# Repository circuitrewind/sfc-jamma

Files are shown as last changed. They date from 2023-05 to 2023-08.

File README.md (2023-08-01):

# sfc-jamma

TLDR: SNES/SFC controller support on arcade machines!

[Click here for a demo video of a Capcom CP Solder used to play Street Fighter Zero 3](https://www.tiktok.com/@vincerants/video/7230315835842170155)

This repository contains the Eagle CAD files as well as the Arduino Nano source code to interface a Super Famicom (SFC) or Super Nintendo (SNES) controller with an Arcade Cabinet JAMMA interface via a 40-pin ribbon cable.

The 40-pin ribbon cable pinout is based on the pinout used by the [EZ Switchers by RiddledTV](https://riddledtv.com/arcade/ez.html). The EZ 4-way Switcher and EZ 8-way Switcher provide both a JAMMA edge and 40-pin output connectors with the intent of having two cabinets wired into the same arcade board for head-to-head gameplay. I abused this fact to instead use the 40-pin cable for a secondary set of user input controls.

Because the wiring on the JAMMA interface and 40-pin interface are tied directly together, the Arduino Nano can also read input from the arcade's input panel, and then forward this information over the Arduino Nano's USB interface back to a PC, such as using it for gamepad emulation. This can be useful for running a PC through an arcade cabinet, and forwarding the input controls from the cabinet back into the PC.

## Button Mappings
On Player 1, hold SELECT + START for two seconds to toggle TEST / SETTINGS button. This is set as a toggle rather than a momentary press because some games like Soul Edge require the button to remain held while in the settings menu.

On Player 2, hold SELECT + START for two seconds to toggle TILT button. P1 and P2 Arduino Nanos run on the same code, which is why this is also a held toggle function.

Press SELECT + UP to select Profile 1
Press SELECT + DOWN to select Profile 2

|SNES|NES|Profile 1|Profile 2|
|---|---|---|---|
|SELECT|SELECT|Insert Coin|Insert Coin|
|START|START|Player Start|Player Start|
|A||Button 5 (MK)|Button 6 (HK)|
|B|A|Button 4 (LK)|Button 4 (LK)|
|X||Button 2 (MP)|Button 3 (HP)|
|Y|B|Button 1 (LP)|Button 1 (LP)|
|L||Button 3 (HP)|Button 2 (MP)|
|R||Button 6 (HK)|Button 5 (MK)|

## Tested SNES Controllers
* Nintendo Super NES Controller: SNS-005
* Nintendo Super Famicom Controller: SHVC-005
* Nintendo Super NES Score Master: SNSP-026
* NTT Data Key Pad: NDK10 (1)
* Brook Gaming Wingman SNES Converter: ZPP005Q
* 8BitDo Retro Receiver for SNES
* Capcom CP Soldier: CP-S01CAN
* HORI Fatal Fury 2 Commander Controller: HSG-07
* HORI Fighting Commander: HSJ-14
* Hudson Soft Super Joycard: HC-691
* Asciiware AsciiPad: AS-131-SP
* Asciiware Super Advantage: 4910
* Asciiware Fight Stick: AS-9981-SF
* STD SN ProPad: SV-334
* STD SN ProgramPad: SV-337
* Triax Turbo Touch 360
* Tyco Super NES Power Plug: 1286
* Konami Hissatsu Command Controller: RU-009
* High Frequency Clear Turbo Controller for SNES
* FC2 Slim
* Hyperkin Retron 2 Controller: M05932

(1) The NTT Data Key Pad will always have bit 14 pressed (outside of the normal buttons). The four high bits are used to identify the type of device plugged into a controller port, with value 0h being a normal controller. This has a value of 2h, and it most likely used by the accompanying hardware to identify itself and tell the software to do extra querying on the controller to read its additional buttons.

## Tested NES Controllers
* Nintendo Controller: NES-004
* Nintendo NES MAX: NES-027
* 8BitDo N30 2.4g Wireless Gamepad: 81BC
* Brook Gaming Wingman SNES Converter: ZPP005Q

## Images
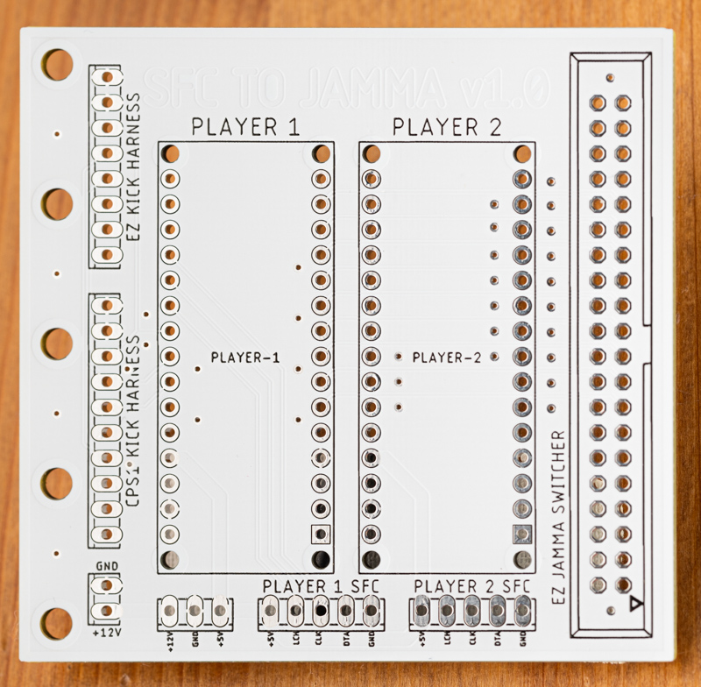
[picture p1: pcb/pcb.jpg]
SFC to JAMMA PCB


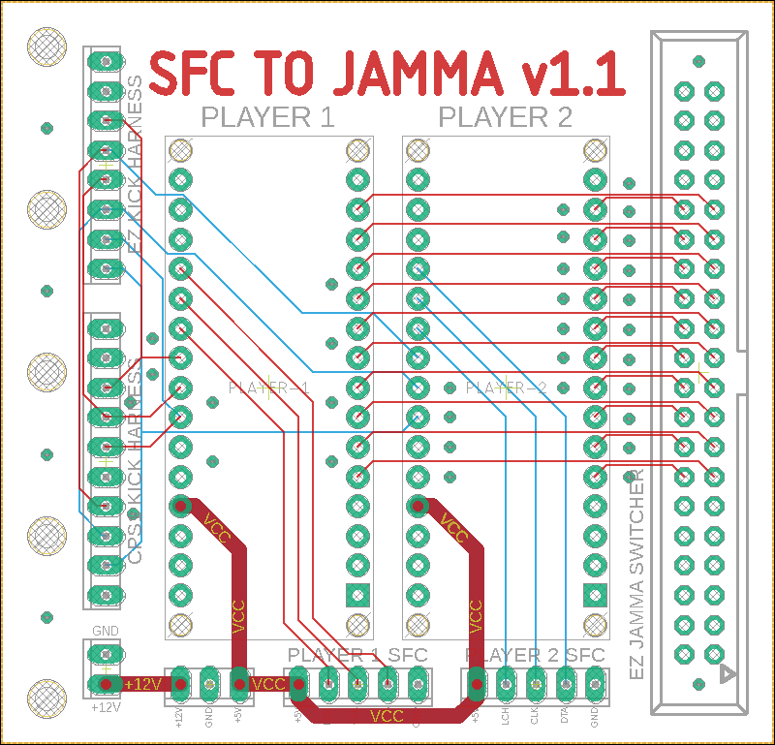
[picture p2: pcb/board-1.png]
SFC to JAMMA Board Layout


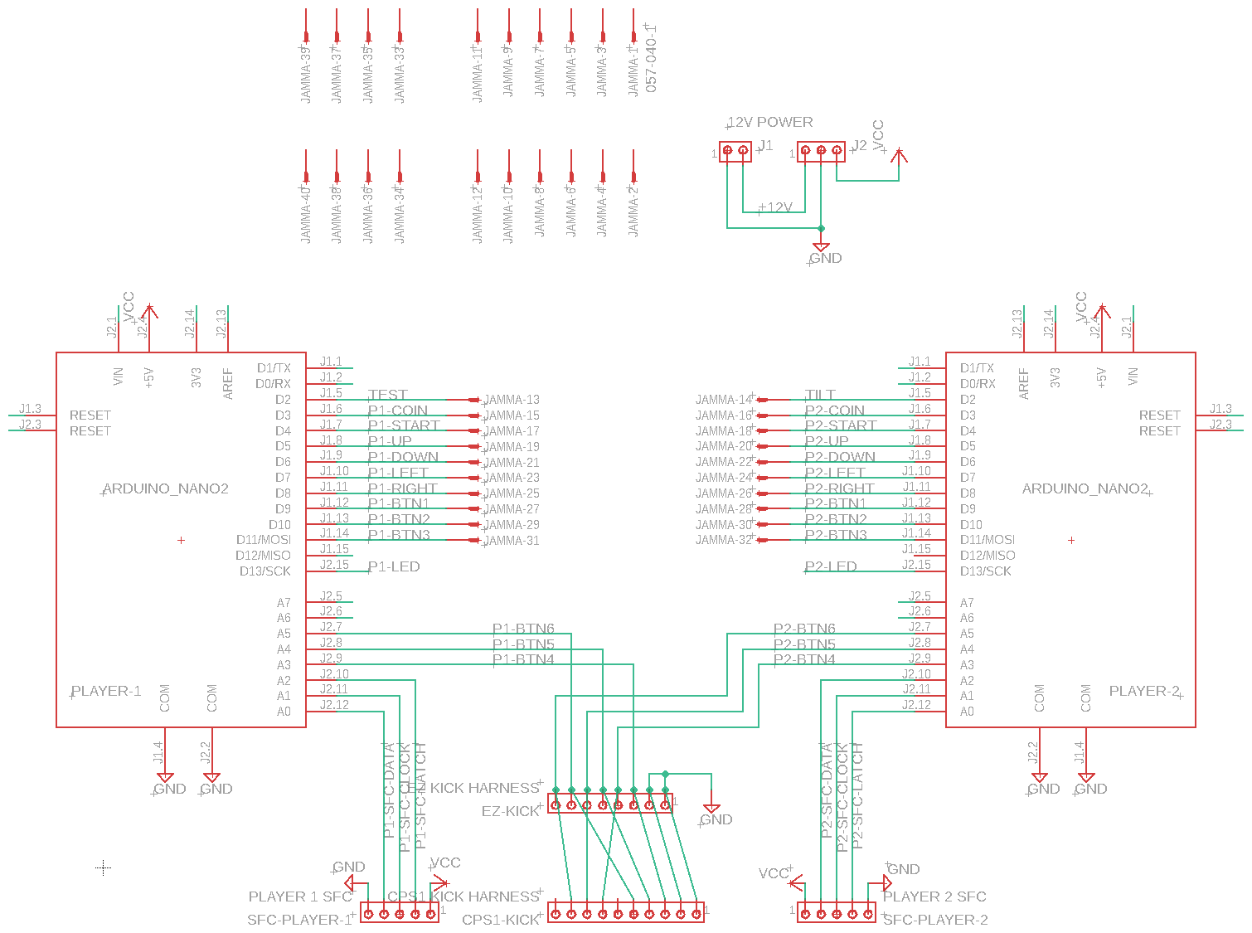
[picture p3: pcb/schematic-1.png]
SFC to JAMMA Schematic


## vJoy IBUS PC Access
To use this board with a PC, allowing SNES/SFC or JAMMA input as a PC gamepad, you'll need a couple of utilities installed and configured on your PC.
* [vJoy](https://sourceforge.net/projects/vjoystick/)
* [vJoySerialFeeder](https://github.com/Cleric-K/vJoySerialFeeder/releases)
* [Video of JAMMA to PC with Street Fighter 6](https://www.tiktok.com/@vincerants/video/7229858727111888174)

### vJoy Configuration
* Download and install [vJoy](https://sourceforge.net/projects/vjoystick/)
* Make sure that "Enable vJoy" is selected
* Uncheck all but "X" and "Y" from Axes
* Set the number of buttons to 16
* Set "POVs" to "0" in the "POV Hat Switch" panel
* Unchecked "Enable Effects" in the "Force Feedback" panel
* Click the "Apply" button

### vJoySerialFeeder Configuration
* Download and run [vJoySerialFeeder](https://github.com/Cleric-K/vJoySerialFeeder/releases)
* Set "Virtual Joystick" to "vJoy.1"
* Set "Protocol" to "IBUS"
* Click the "Setup" button next to "IBUS" and enable "Use 16-bit channels (Arduino)"
* Set "Port" to the COM port your Arduino Nano is registering to on your PC
* Click "Add Bit-mapped Button" once and "Add Axis" twice to add the three channels this board provides
* Set the "Bits" channel to "1", and configure the individual buttons as: 1, 3, 7, 8, nc, nc, nc, nc, 2, 4, 5, 6, nc, nc, nc, nc
* Set the axis channels to 2 for X, and 3 for Y
* In each axis channel, click their "Setup" button and set: Minimum=0, Center=32768, Maximum=65535
* Once everything is configured click on the "Connect" button to activate the interface

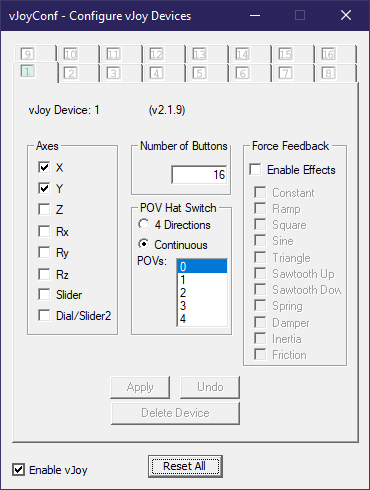
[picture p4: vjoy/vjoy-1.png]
vJoy configuration screen


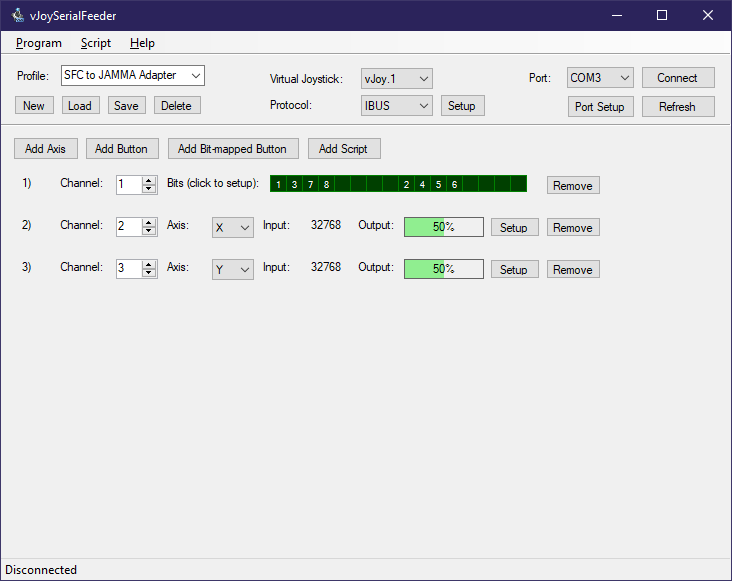
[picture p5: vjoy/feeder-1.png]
vJoySerialFeeder configuration screen


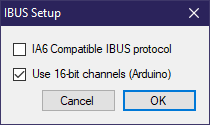
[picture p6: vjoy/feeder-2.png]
vJoySerialFeeder IBUS configuration screen


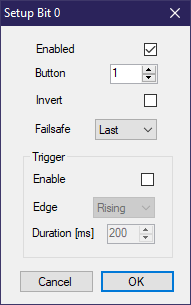
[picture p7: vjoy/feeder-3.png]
vJoySerialFeeder bit-mapped button configuration screen


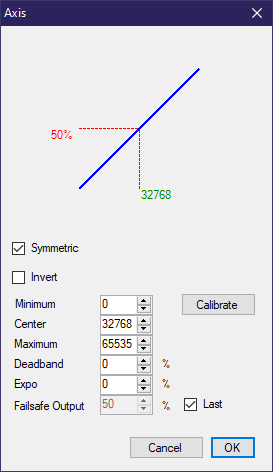
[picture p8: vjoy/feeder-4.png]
vJoySerialFeeder axis configuration screen


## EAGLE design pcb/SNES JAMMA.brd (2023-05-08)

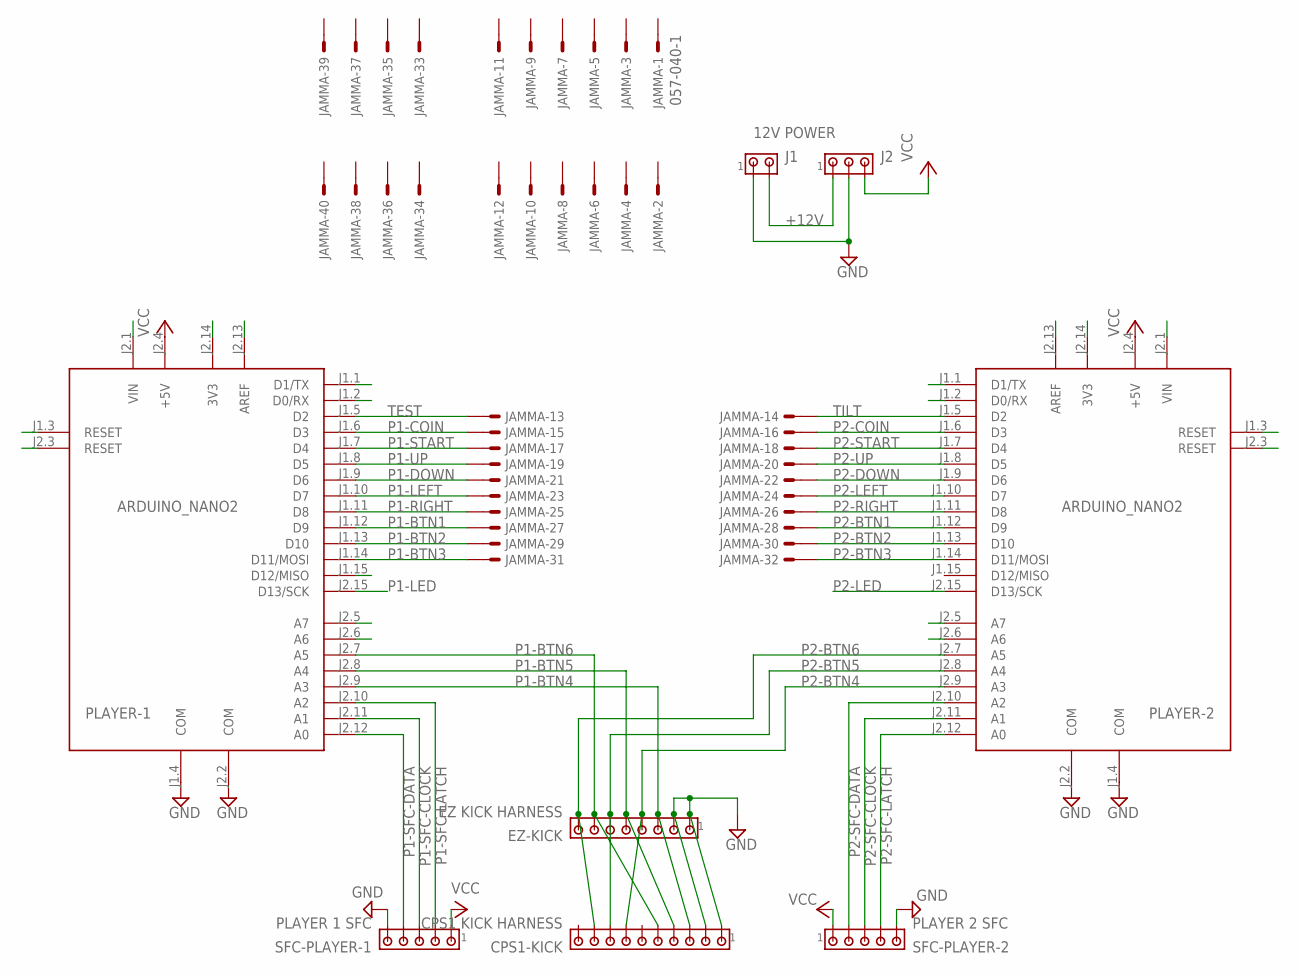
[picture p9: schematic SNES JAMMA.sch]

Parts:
CPS1-KICK: CPS1 KICK HARNESS; 10X10MTA
EZ-KICK: EZ KICK HARNESS; 10X08MTA
J1: 12V POWER; 10X02MTA
J2: MTA03-100; 10X03MTA
JAMMA: 057-040-1
PLAYER-1, PLAYER-2: ARDUINO_NANO2
SFC-PLAYER-1: PLAYER 1 SFC; 10X05MTA
SFC-PLAYER-2: PLAYER 2 SFC; 10X05MTA

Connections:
+12V: J1.2, J2.1
GND: CPS1-KICK.1, CPS1-KICK.2, EZ-KICK.1, EZ-KICK.2, J1.1, J2.2, PLAYER-1.J1.4 (COM), PLAYER-1.J2.2 (COM), PLAYER-2.J1.4 (COM), PLAYER-2.J2.2 (COM), SFC-PLAYER-1.5, SFC-PLAYER-2.5
P1-BTN1: JAMMA.27, PLAYER-1.J1.12 (D9)
P1-BTN2: JAMMA.29, PLAYER-1.J1.13 (D10)
P1-BTN3: JAMMA.31, PLAYER-1.J1.14 (D11/MOSI)
P1-BTN4: CPS1-KICK.3, EZ-KICK.3, PLAYER-1.J2.9 (A3)
P1-BTN5: CPS1-KICK.4, EZ-KICK.5, PLAYER-1.J2.8 (A4)
P1-BTN6: CPS1-KICK.5, EZ-KICK.7, PLAYER-1.J2.7 (A5)
P1-COIN: JAMMA.15, PLAYER-1.J1.6 (D3)
P1-DOWN: JAMMA.21, PLAYER-1.J1.9 (D6)
P1-LED: PLAYER-1.J2.15 (D13/SCK)
P1-LEFT: JAMMA.23, PLAYER-1.J1.10 (D7)
P1-RIGHT: JAMMA.25, PLAYER-1.J1.11 (D8)
P1-SFC-CLOCK: PLAYER-1.J2.11 (A1), SFC-PLAYER-1.3
P1-SFC-DATA: PLAYER-1.J2.12 (A0), SFC-PLAYER-1.4
P1-SFC-LATCH: PLAYER-1.J2.10 (A2), SFC-PLAYER-1.2
P1-START: JAMMA.17, PLAYER-1.J1.7 (D4)
P1-UP: JAMMA.19, PLAYER-1.J1.8 (D5)
P2-BTN1: JAMMA.28, PLAYER-2.J1.12 (D9)
P2-BTN2: JAMMA.30, PLAYER-2.J1.13 (D10)
P2-BTN3: JAMMA.32, PLAYER-2.J1.14 (D11/MOSI)
P2-BTN4: CPS1-KICK.7, EZ-KICK.4, PLAYER-2.J2.9 (A3)
P2-BTN5: CPS1-KICK.8, EZ-KICK.6, PLAYER-2.J2.8 (A4)
P2-BTN6: CPS1-KICK.9, EZ-KICK.8, PLAYER-2.J2.7 (A5)
P2-COIN: JAMMA.16, PLAYER-2.J1.6 (D3)
P2-DOWN: JAMMA.22, PLAYER-2.J1.9 (D6)
P2-LED: PLAYER-2.J2.15 (D13/SCK)
P2-LEFT: JAMMA.24, PLAYER-2.J1.10 (D7)
P2-RIGHT: JAMMA.26, PLAYER-2.J1.11 (D8)
P2-SFC-CLOCK: PLAYER-2.J2.11 (A1), SFC-PLAYER-2.3
P2-SFC-DATA: PLAYER-2.J2.12 (A0), SFC-PLAYER-2.4
P2-SFC-LATCH: PLAYER-2.J2.10 (A2), SFC-PLAYER-2.2
P2-START: JAMMA.18, PLAYER-2.J1.7 (D4)
P2-UP: JAMMA.20, PLAYER-2.J1.8 (D5)
TEST: JAMMA.13, PLAYER-1.J1.5 (D2)
TILT: JAMMA.14, PLAYER-2.J1.5 (D2)
VCC: J2.3, PLAYER-1.J2.4 (+5V), PLAYER-2.J2.4 (+5V), SFC-PLAYER-1.1, SFC-PLAYER-2.1

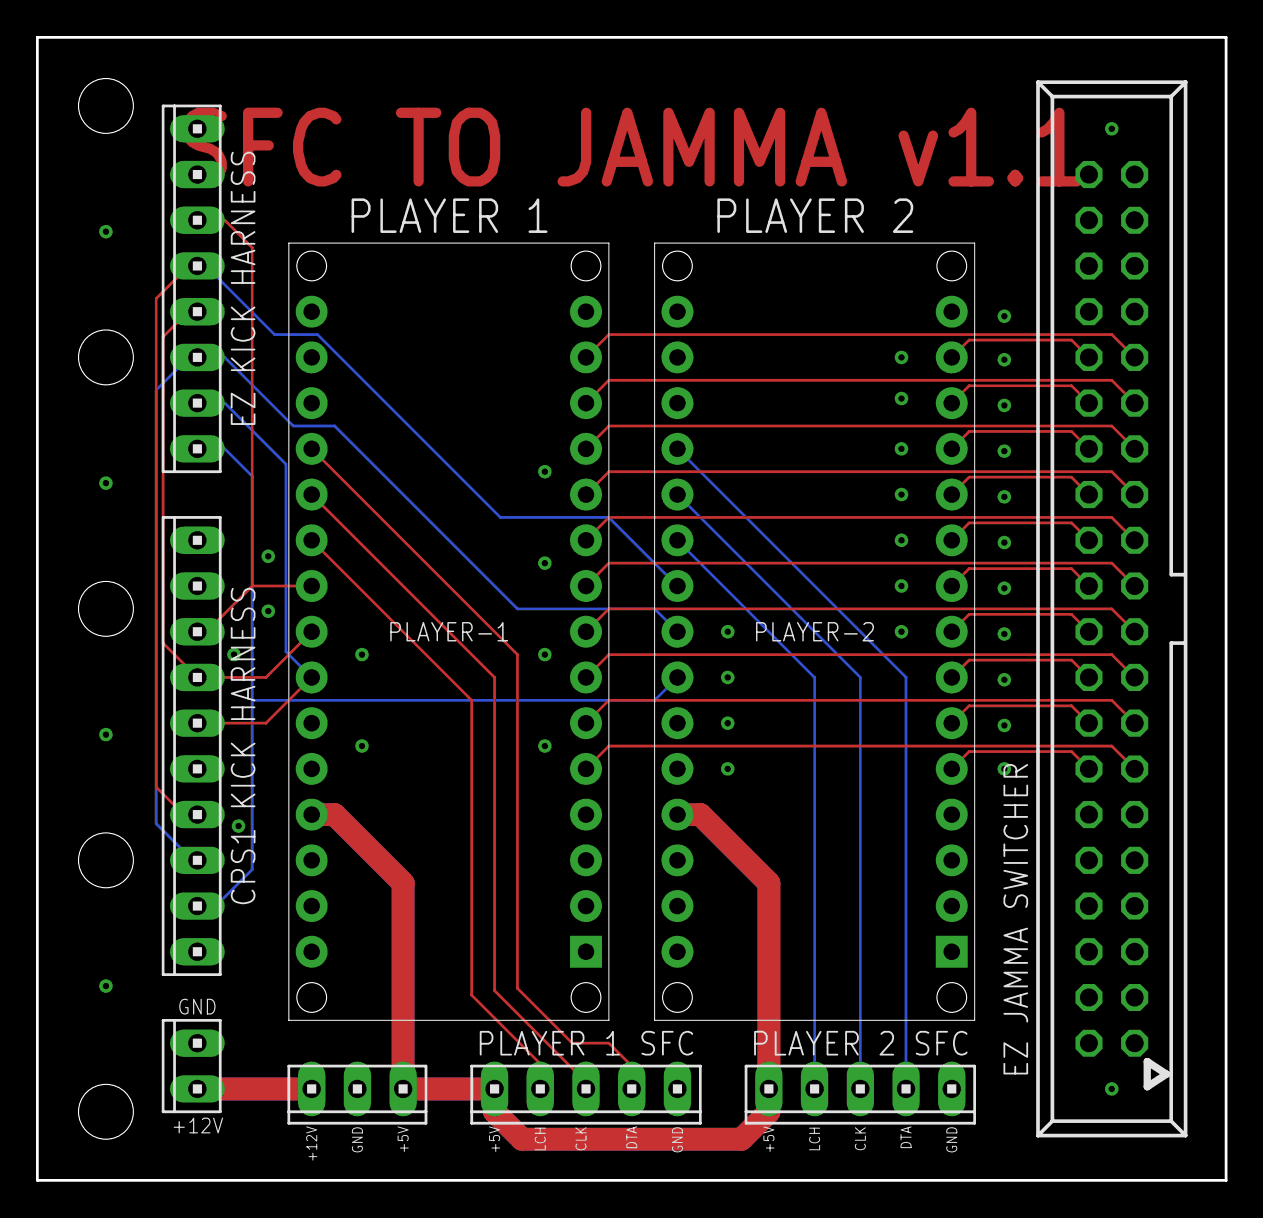
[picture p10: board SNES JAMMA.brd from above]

Board: 2 copper layers, 66.0 x 63.5 mm, 9 parts (0 on the bottom side), 35 nets.

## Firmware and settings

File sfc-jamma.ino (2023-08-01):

////////////////////////////////////////////////////////////////////////////////
// SFC PROFILE CONFIGURATION
////////////////////////////////////////////////////////////////////////////////
#define BUTTON_MAX    (16)
#define PROFILE_MAX    (2)
int profile             = 0;
unsigned int  held_btns = 0;
unsigned long held_time = 0;
bool          held_test = false;




////////////////////////////////////////////////////////////////////////////////
// SFC PIN CONFIGURATION
////////////////////////////////////////////////////////////////////////////////
#define DATA_SERIAL   (14)
#define DATA_CLOCK    (15)
#define DATA_LATCH    (16)




////////////////////////////////////////////////////////////////////////////////
// JAMMA BUTTON 
////////////////////////////////////////////////////////////////////////////////
#define P1_TEST        (2)
#define P1_COIN        (3)
#define P1_START       (4)
#define P1_UP          (5)
#define P1_DOWN        (6)
#define P1_LEFT        (7)
#define P1_RIGHT       (8)
#define P1_LP          (9)
#define P1_MP         (10)
#define P1_HP         (11)
#define P1_LK         (17)
#define P1_MK         (18)
#define P1_HK         (19)




////////////////////////////////////////////////////////////////////////////////
// IBUS CONFIGURATION FOR SENDING BUTTONS BACK TO
// PC OVER SERIAL/USB INTERFACE
////////////////////////////////////////////////////////////////////////////////
#define ibus_baud     (115200)
#define ibus_sep      (0x40)
#define ibus_channels (3)
#define ibus_len      (4 + (ibus_channels * 2))
int ibus_checksum     = 0;




////////////////////////////////////////////////////////////////////////////////
// CONSTANT TIME DELAY CODE
// BROOK SNES ADAPTERS ARE UNSTABLE AT 6MS, BUT STABLE AT 7MS
// ADD AN EXTRA 0.5MS TO ENSURE A MARGIN OF ERROR
////////////////////////////////////////////////////////////////////////////////
unsigned long time;
#define time_delay    (7500)




////////////////////////////////////////////////////////////////////////////////
// BUTTON MAPPING PROFILES
////////////////////////////////////////////////////////////////////////////////
const byte P1[PROFILE_MAX][BUTTON_MAX] = {
  {
    P1_LK,
    P1_LP,
    P1_COIN,
    P1_START,
    P1_UP,
    P1_DOWN,
    P1_LEFT,
    P1_RIGHT,
    P1_MK,
    P1_MP,
    P1_HP,
    P1_HK,
    0xFF,
    0xFF,
    0xFF,
    0xFF,
  }, {
    P1_LK,
    P1_LP,
    P1_COIN,
    P1_START,
    P1_UP,
    P1_DOWN,
    P1_LEFT,
    P1_RIGHT,
    P1_HK,
    P1_HP,
    P1_MP,
    P1_MK,
    0xFF,
    0xFF,
    0xFF,
    0xFF,
  }
};




////////////////////////////////////////////////////////////////////////////////
// READ DATA FROM THE SFC SERIAL BUS
////////////////////////////////////////////////////////////////////////////////
unsigned int read_button() {
  unsigned int buttons = 0x0000;

  // INITIATE A LATCHING SEQUENCE
  digitalWrite(DATA_LATCH, HIGH);
  delayMicroseconds(12);
  digitalWrite(DATA_LATCH, LOW);

  // LOOP THROUGH EACH BUTTON AND READ ITS VALUE
  for(int i=0; i<BUTTON_MAX; i++){
    delayMicroseconds(6);
    digitalWrite(DATA_CLOCK, LOW);
    delayMicroseconds(6);
    buttons |= (!!digitalRead(DATA_SERIAL)) << i;
    digitalWrite(DATA_CLOCK, HIGH);
  }

  // CONTROLLER APPEARS UNPLUGGED
  // PROCESS AS NO BUTTONS PRESSED INSTEAD
  if (buttons == 0x0000) buttons = 0xFFFF;

  // NES CONTROLLER SUPPORT
  // UNSET HIGH BITS IF WE DETECT 8-BIT NES CONTROLLERS
  if ((buttons & 0xFF00) == 0x0000) {
    buttons |= 0xFF00;
  }

  return buttons;
}




////////////////////////////////////////////////////////////////////////////////
// BEGIN AN IBUS TRANSMISSION
////////////////////////////////////////////////////////////////////////////////
void ibus_start() {
  ibus_checksum = 0xffff - ibus_len - ibus_sep;
  Serial.write(ibus_len);
  Serial.write(ibus_sep);
}




////////////////////////////////////////////////////////////////////////////////
// END AN IBUS TRANSMISSION
////////////////////////////////////////////////////////////////////////////////
void ibus_end() {
  Serial.write(ibus_checksum & 0xff);
  Serial.write(ibus_checksum >> 8);
}




////////////////////////////////////////////////////////////////////////////////
// SEND AN IBUS MESASGE
////////////////////////////////////////////////////////////////////////////////
void ibus_write(unsigned short data) {
  // WRITE FIRST BYTE
  byte b = data & 0xff;
  Serial.write(b);
  ibus_checksum -= b;

  // WRITE SECOND BYTE
  b = data >> 8;
  Serial.write(b);
  ibus_checksum -= b;
}




////////////////////////////////////////////////////////////////////////////////
// TOGGLE TEST/SETTINGS BUTTON WHEN START+SELECT HELD FOR 2 SECONDS
////////////////////////////////////////////////////////////////////////////////
void test_button() {
  if (micros() - held_time < 2000000) return;

  held_btns = 0x0000;
  held_test = !held_test;

  if (held_test) {
    pinMode(P1_TEST, OUTPUT);
    digitalWrite(P1_TEST, LOW);
  } else {
    pinMode(P1_TEST, INPUT_PULLUP);
  }
}




////////////////////////////////////////////////////////////////////////////////
// MAIN INITIALIZATION CODE
////////////////////////////////////////////////////////////////////////////////
void setup() {
  
  // initialize pin LED_BUILTIN as an output.
  pinMode(LED_BUILTIN, OUTPUT);
  digitalWrite(LED_BUILTIN, LOW);

  // INITIALIZE PIN FOR TEST MODE
  pinMode(P1_TEST, INPUT_PULLUP);

  // SET ALL JAMMA PINS TO "INPUT" MODE
  for (int i=0; i<BUTTON_MAX; i++) {
    if (P1[profile][i] == 0xFF) continue;
    pinMode(P1[profile][i], INPUT_PULLUP);
  }
  
  // SET DATA_CLOCK NORMALLY HIGH
  pinMode(DATA_CLOCK, OUTPUT);
  digitalWrite(DATA_CLOCK, HIGH);
  
  // SET DATA_LATCH NORMALLY LOW
  pinMode(DATA_LATCH, OUTPUT);
  digitalWrite(DATA_LATCH, LOW);

  // SET DATA_SERIAL NORMALLY HIGH
  pinMode(DATA_SERIAL, OUTPUT);
  digitalWrite(DATA_SERIAL, HIGH);
  pinMode(DATA_SERIAL, INPUT_PULLUP);

  // SETUP SERIAL FOR IBUS
  Serial.begin(ibus_baud);

  // GET INITIAL TIMEFRAME
  time = micros();
}




////////////////////////////////////////////////////////////////////////////////
// MAIN PROGRAM LOOP
////////////////////////////////////////////////////////////////////////////////
void loop() {
  // READ THE CURRENT BUTTON STATE
  unsigned int    buttons = read_button();
  unsigned int    jamma   = 0;
  unsigned short  jamma_x = 0x8000;
  unsigned short  jamma_y = 0x8000;


  // LIGHT UP ARDUINO LED IF ANY SFC BUTTONS ARE PRESSED
  digitalWrite(LED_BUILTIN, (buttons != 0xFFFF));


  // BUTTON STATE CHANGED FROM LAST POLL TIME
  if (held_btns != buttons) {
    held_btns = buttons;
    held_time = micros();
  }


  // SWITCH BETWEEN JAMMA BUTTON MAPPING PROFILES
  switch (~buttons) {
    case 0x0014:  profile = 0;    break;
    case 0x0024:  profile = 1;    break;

    // TEST BUTTON TOGGLE
    case 0x000C:  test_button();  break;
  }


  // PROCESS BUTTON DATA
  for (int i=0; i<BUTTON_MAX; i++) {
    int btn = P1[profile][i];
    if (btn == 0xFF) continue;


    // SFC BUTTON NOT PRESSED, READ JAMMA BUTTON INSTEAD
    if (buttons & (0x01 << i)) {
      pinMode(btn, INPUT_PULLUP);
      if (digitalRead(btn) == LOW) {
        jamma |= (0x01 << i);

        // PROCESS ARCADE JOYSTICK
        switch (btn) {
          case P1_LEFT:   jamma_x = 0x0000; break;
          case P1_RIGHT:  jamma_x = 0xffff; break;
          case P1_UP:     jamma_y = 0x0000; break;
          case P1_DOWN:   jamma_y = 0xffff; break;
        }
      }


    // SEND SFC BUTTON PRESS TO JAMMA
    } else {
      pinMode(btn, OUTPUT);
      digitalWrite(btn, LOW);

      // PROCESS SFC D-PAD
      switch (btn) {
        case P1_LEFT:   jamma_x = 0x0000; break;
        case P1_RIGHT:  jamma_x = 0xffff; break;
        case P1_UP:     jamma_y = 0x0000; break;
        case P1_DOWN:   jamma_y = 0xffff; break;
      }
    }
  }


  // SEND SFC AND JAMMA BUTTON STATUS TO IBUS
  ibus_start();
  ibus_write(jamma | (~buttons));
  ibus_write(jamma_x);
  ibus_write(jamma_y);
  ibus_end();

  
  // DELAY REQUIRED FOR BROOK ADAPTER COMPATIBILITY
  // USE A CONSTANT TIME DELAY REGARDLESS OF PROCESSING ABOVE
  while ((micros() - time) < time_delay) {}
  time += time_delay;
}

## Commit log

2023-03-23 Adding PCB files
    [SNES JAMMA.brd, SNES JAMMA.sch]
2023-03-23 Adding Arduino code (flash this to both P1 and P2, they're identical)
2023-05-05 SCF to JAMMA v1.0
    [sfc-jamma.ino]
2023-05-05 v1.0 PCB and Schematics files
    [SNES JAMMA.brd, SNES JAMMA.sch]
2023-05-06 Experimental IBUS addition to firmware NOTE: this will change soon, I want to break out directionals and change button mappings, and recombine SFC and JAMMA inputs on IBUS (probably as 3 separate cha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
    [sfc-jamma.ino]
2023-05-07 Board feels stable now, so removing debug ibus channels Adding JAMMA arcade stick to ibus dpad inputs
    [sfc-jamma.ino]
2023-05-07 Updating board design to v1.1 Adding ability for P1 Arduino to trigger "test" switch
    [SNES JAMMA.brd, SNES JAMMA.sch]
2023-05-08 Adding ability to swap between JAMMA button mapping profiles
    [sfc-jamma.ino]
2023-05-08 Adding in board revision v1.1 support: TEST MODE BUTTON!
    NOTE: toggle test button/switch by holding START+SELECT for 2 seconds. This is a toggle rather than a momentary press because games like Soul Edge require the button to be held down to remain in the 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
    Other than adding more button mappings in the future, this will probably be the final firmware revision
2023-05-08 Forgot a comment line. Doesn't effect compiled firmware tho :P
    [sfc-jamma.ino]
2023-05-08 Adding button mapping info to the README.md file
2023-05-08 Correcting P1 TEST toggle incorrectly being wired to TILT instead P1 TEST is now properly TEST toggle Additionally, P2's is now wired into TILT so they're both available to be used!
    [SNES JAMMA.brd, SNES JAMMA.sch]
2023-05-08 Adding in the vJoy configuration instructions to use this board as a JAMMA to PC interface
